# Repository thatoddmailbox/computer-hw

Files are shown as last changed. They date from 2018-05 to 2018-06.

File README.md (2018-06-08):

# computer-hw
Hardware for the Soviet-era microcomputer I built. See [this repository](https://github.com/thatoddmailbox/computer) for more information.

Most of the files in this respository are in KiCad format and require KiCad 4.0.7 to view; however, if you just want to view the schematic, you can find a PDF version in the doc folder or linked in the list below.

## Helpful documentation
* [Schematic in PDF format](./doc/schematic.pdf)
* [Original plan for memory decoding](./doc/decoding_original_plan.jpeg)
* [Changes to memory decoding when ROM and RAM chips didn't work](./doc/decoding_workaround.jpeg)
* [High-quality mechanical drawing for ZIF socket](./doc/zif_mechanical_drawing.jpeg)

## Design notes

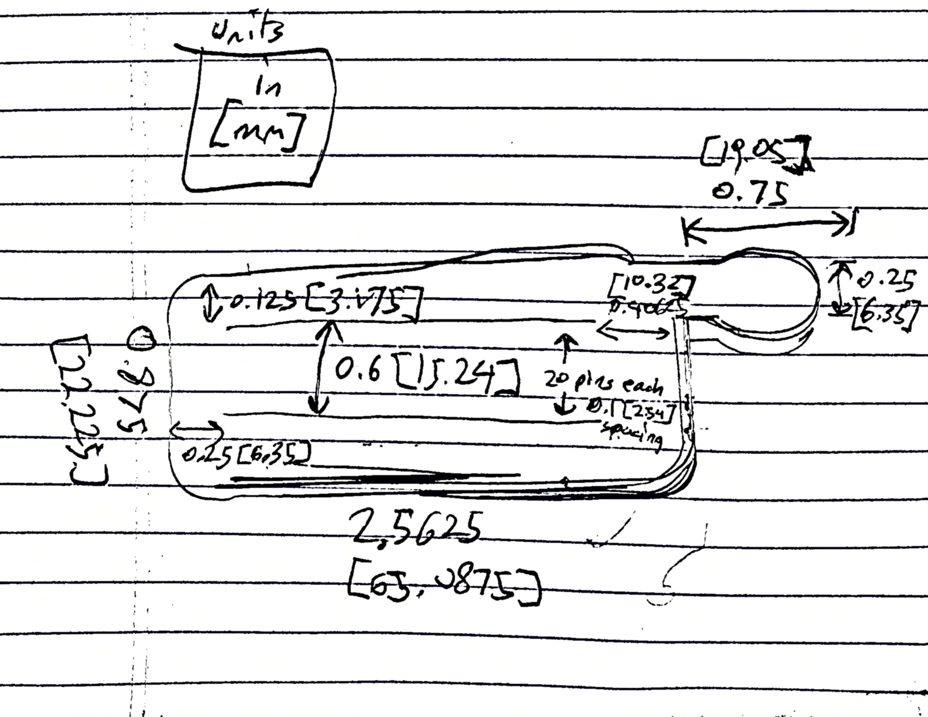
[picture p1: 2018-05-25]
doc/zif_mechanical_drawing.jpeg

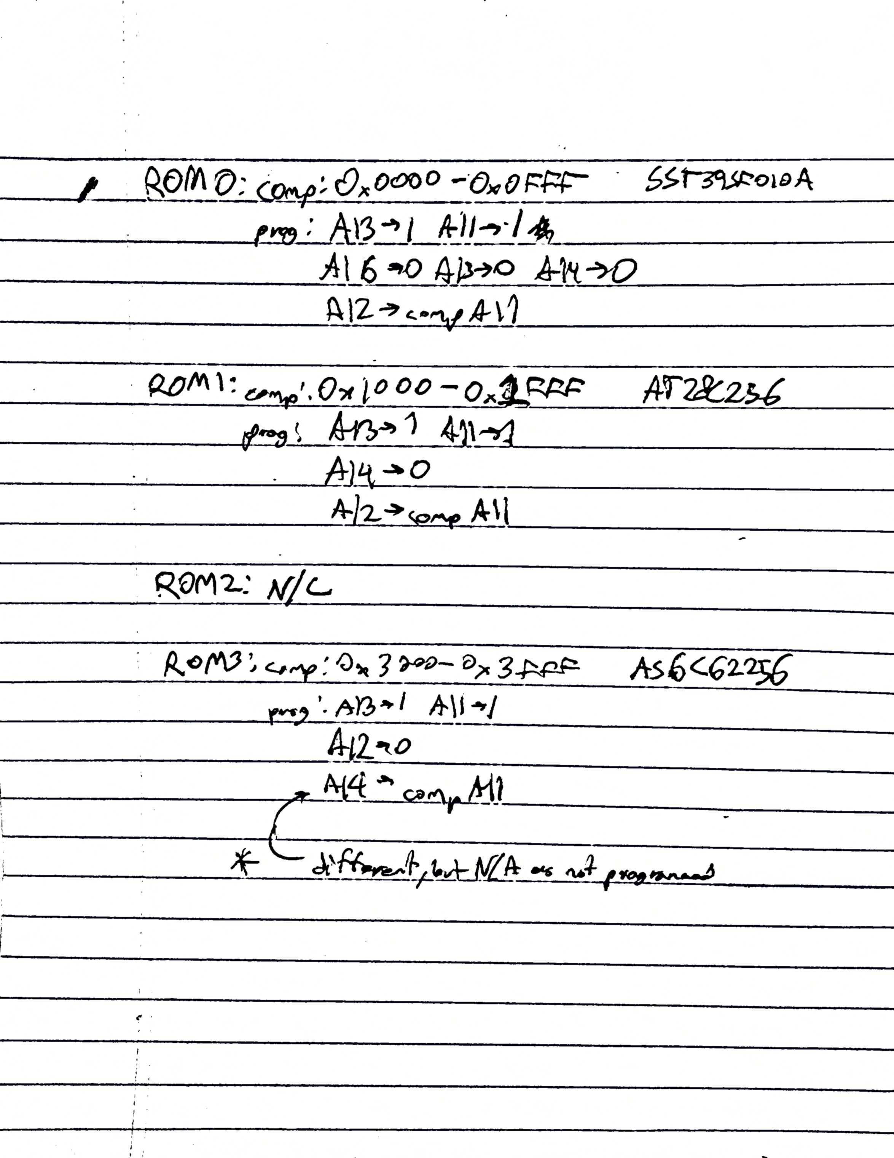
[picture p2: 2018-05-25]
doc/decoding_workaround.jpeg

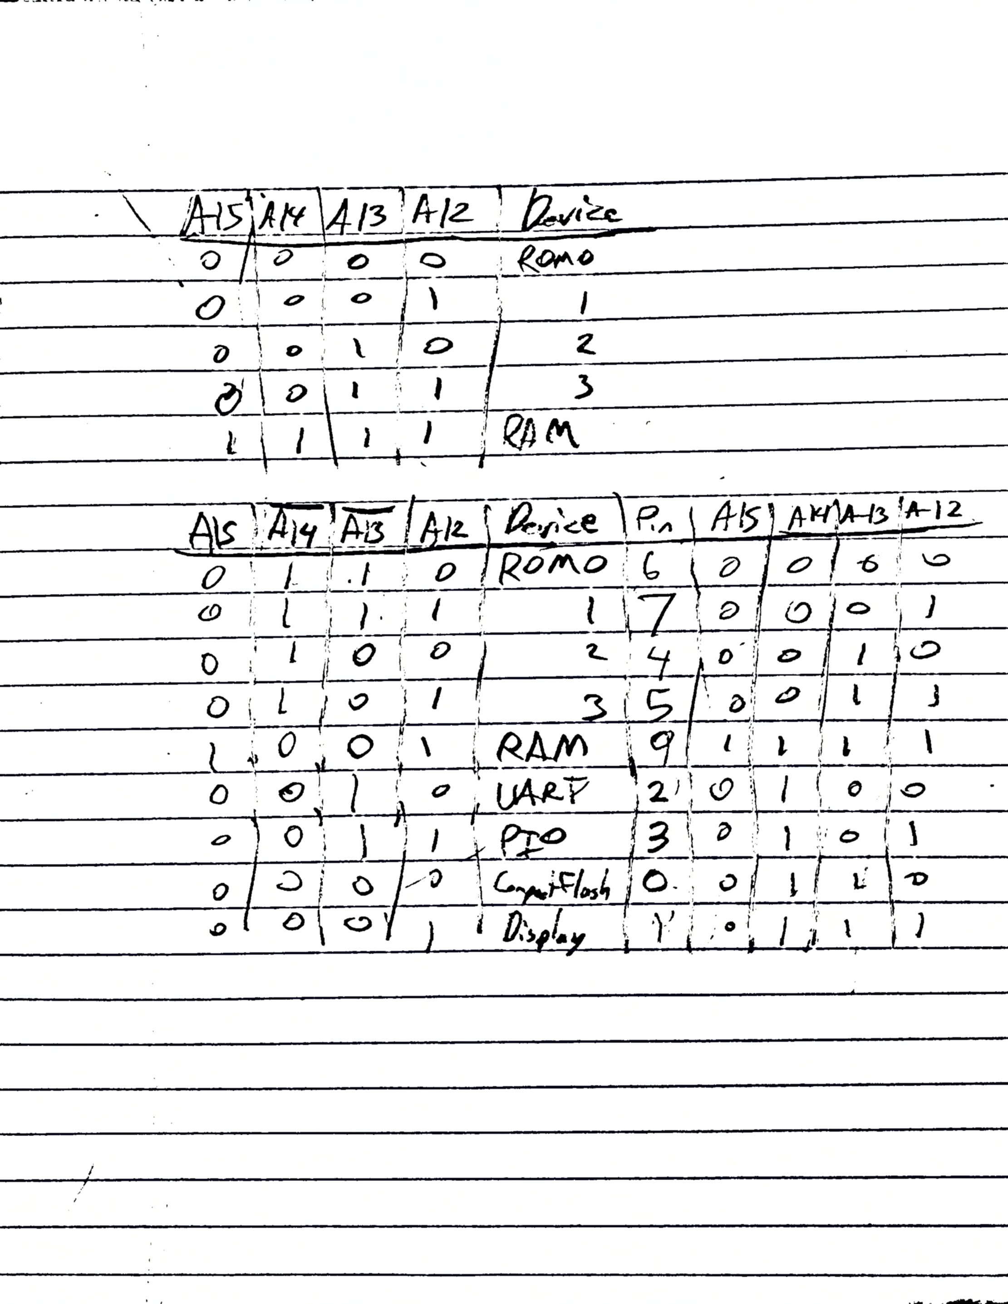
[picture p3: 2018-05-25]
doc/decoding_original_plan.jpeg

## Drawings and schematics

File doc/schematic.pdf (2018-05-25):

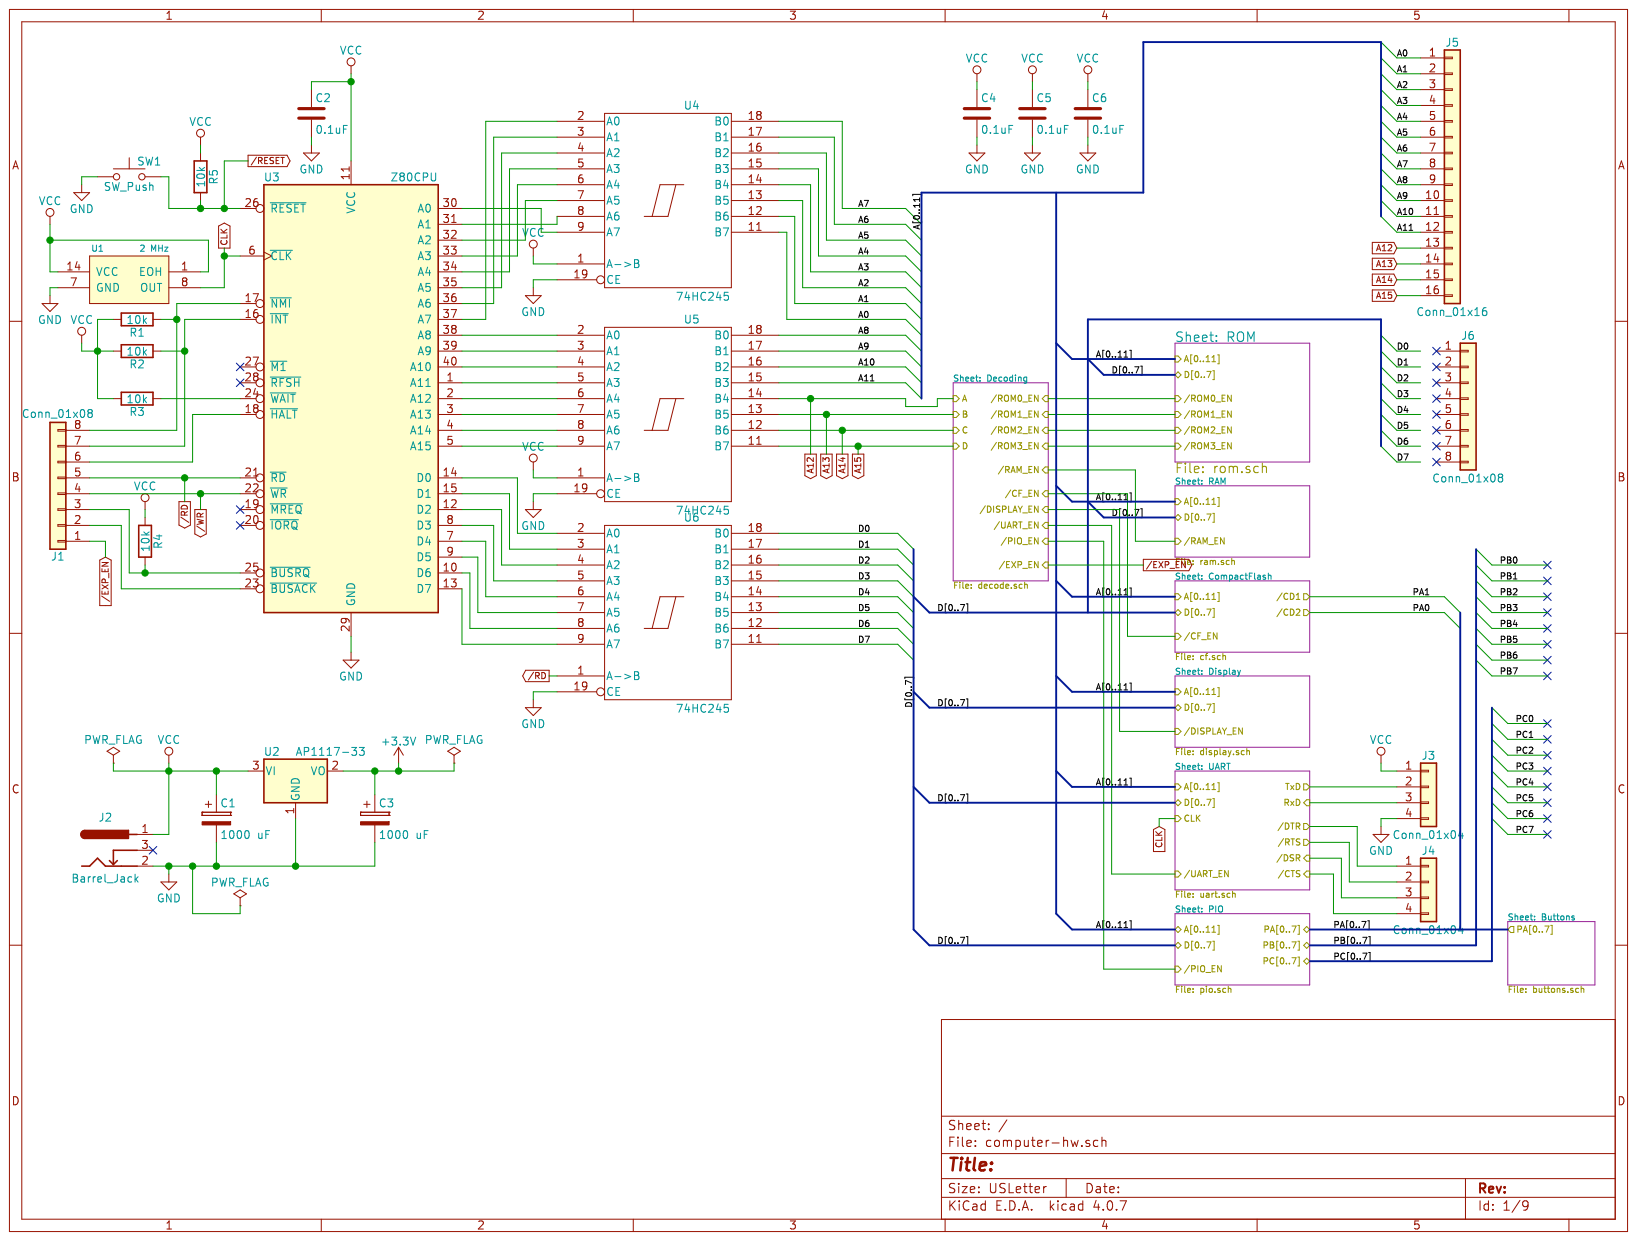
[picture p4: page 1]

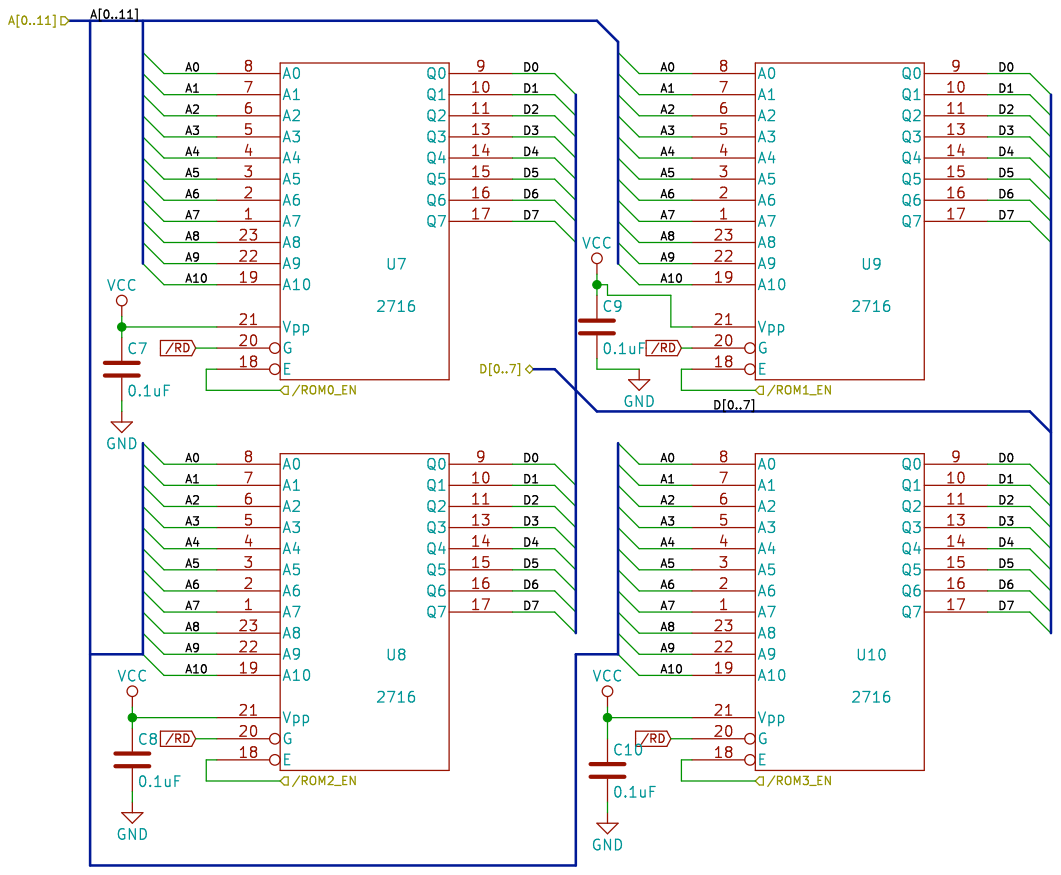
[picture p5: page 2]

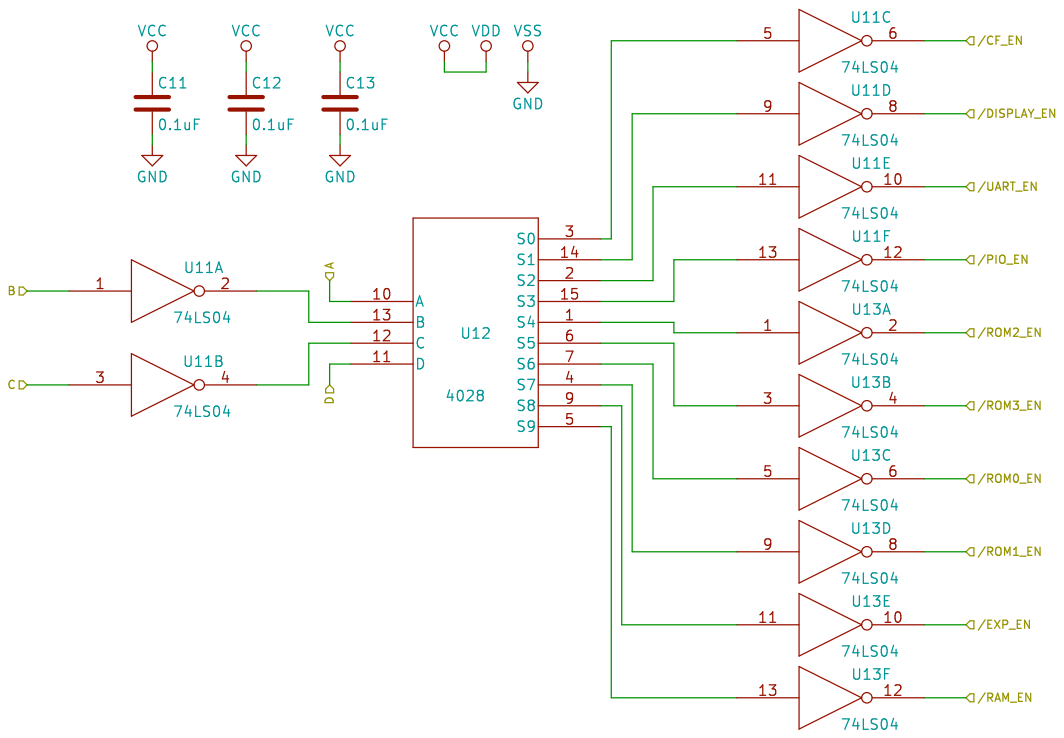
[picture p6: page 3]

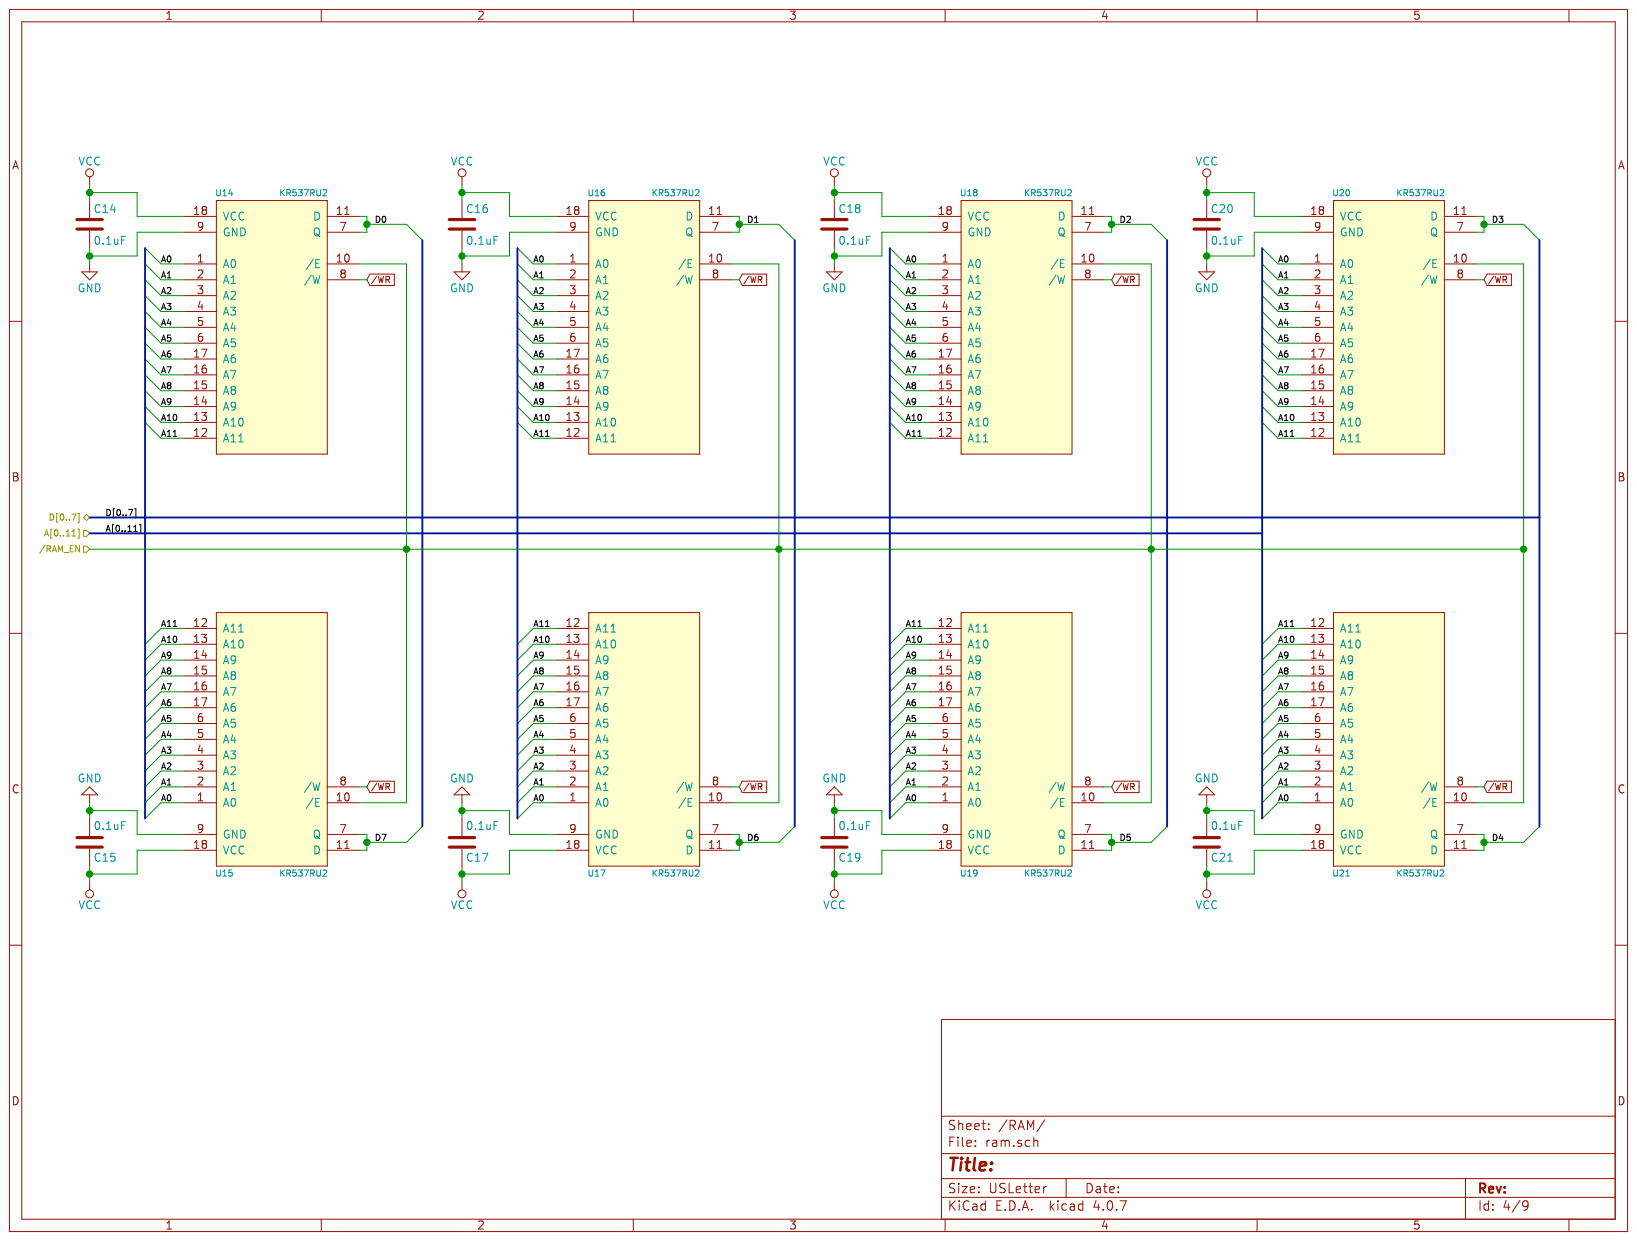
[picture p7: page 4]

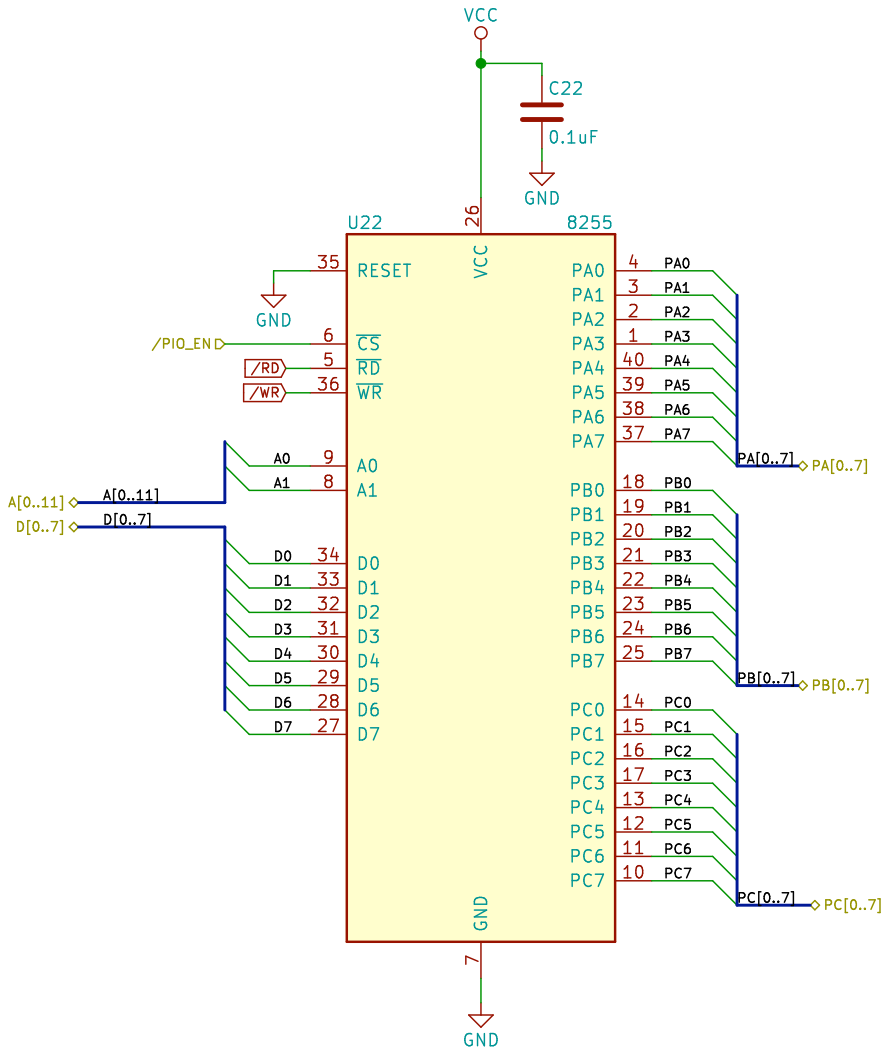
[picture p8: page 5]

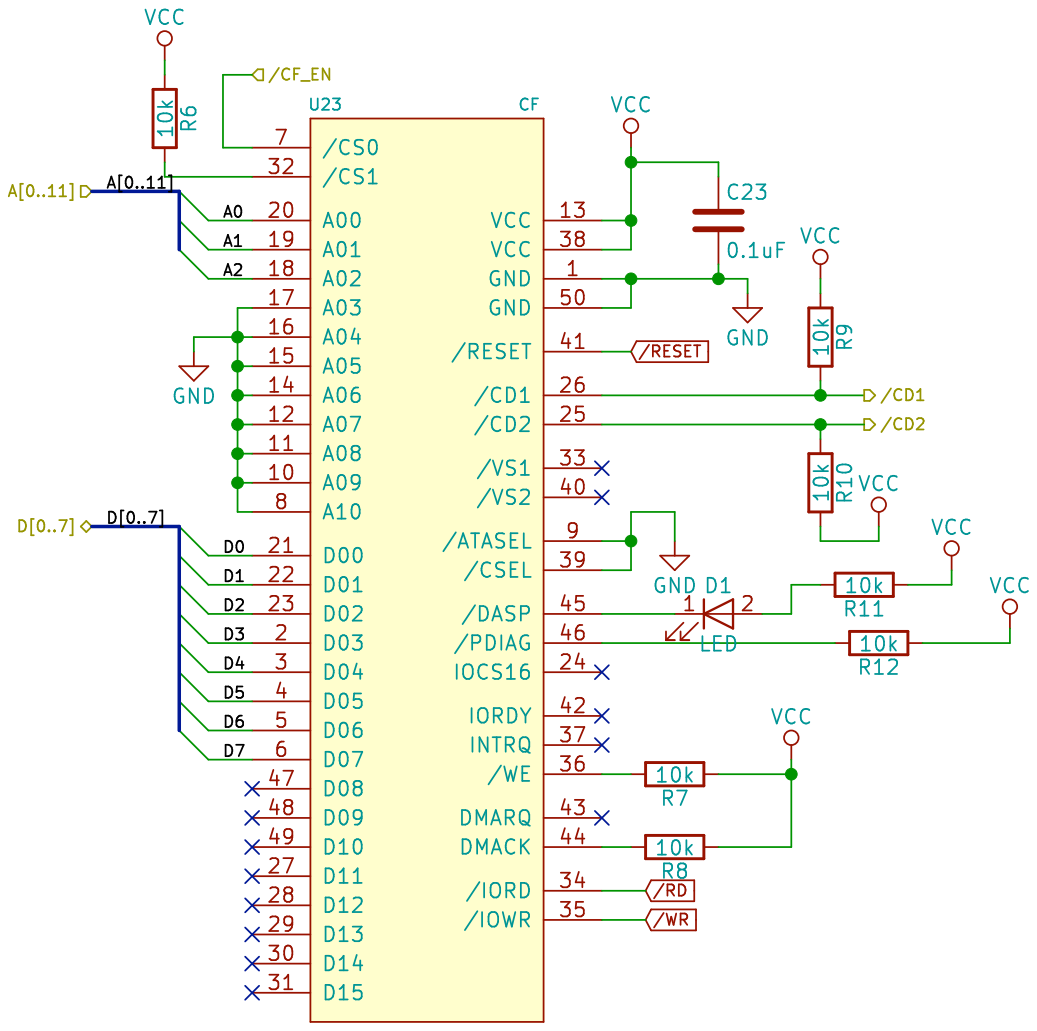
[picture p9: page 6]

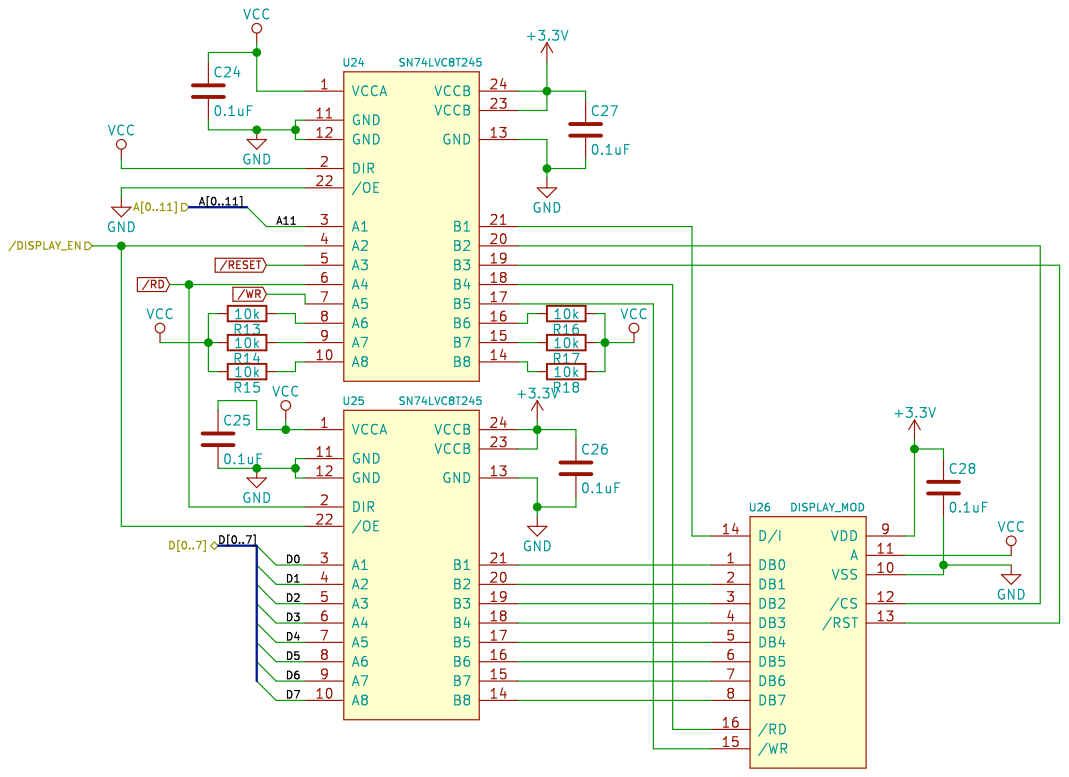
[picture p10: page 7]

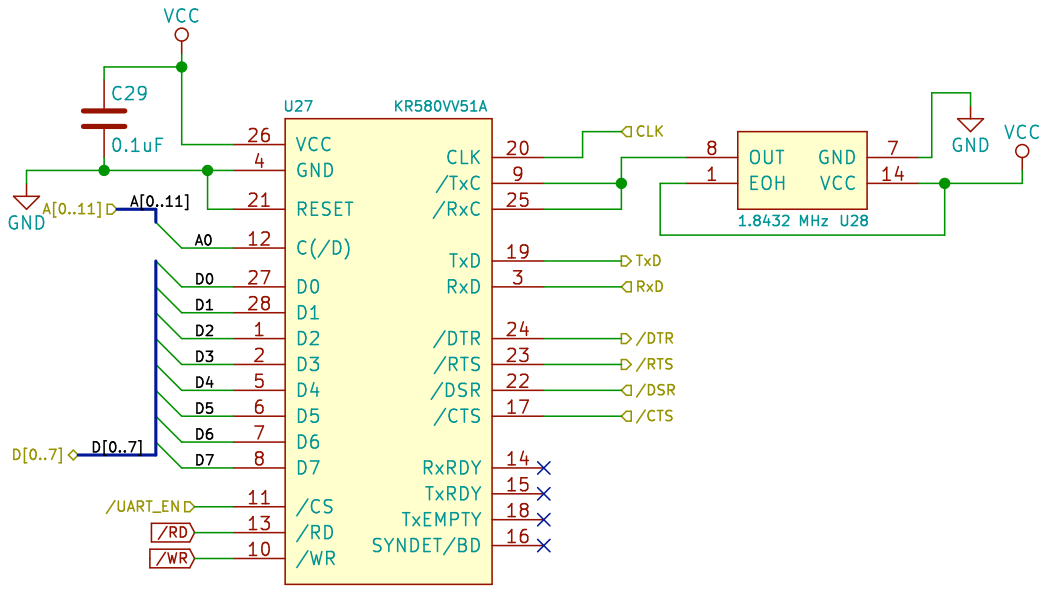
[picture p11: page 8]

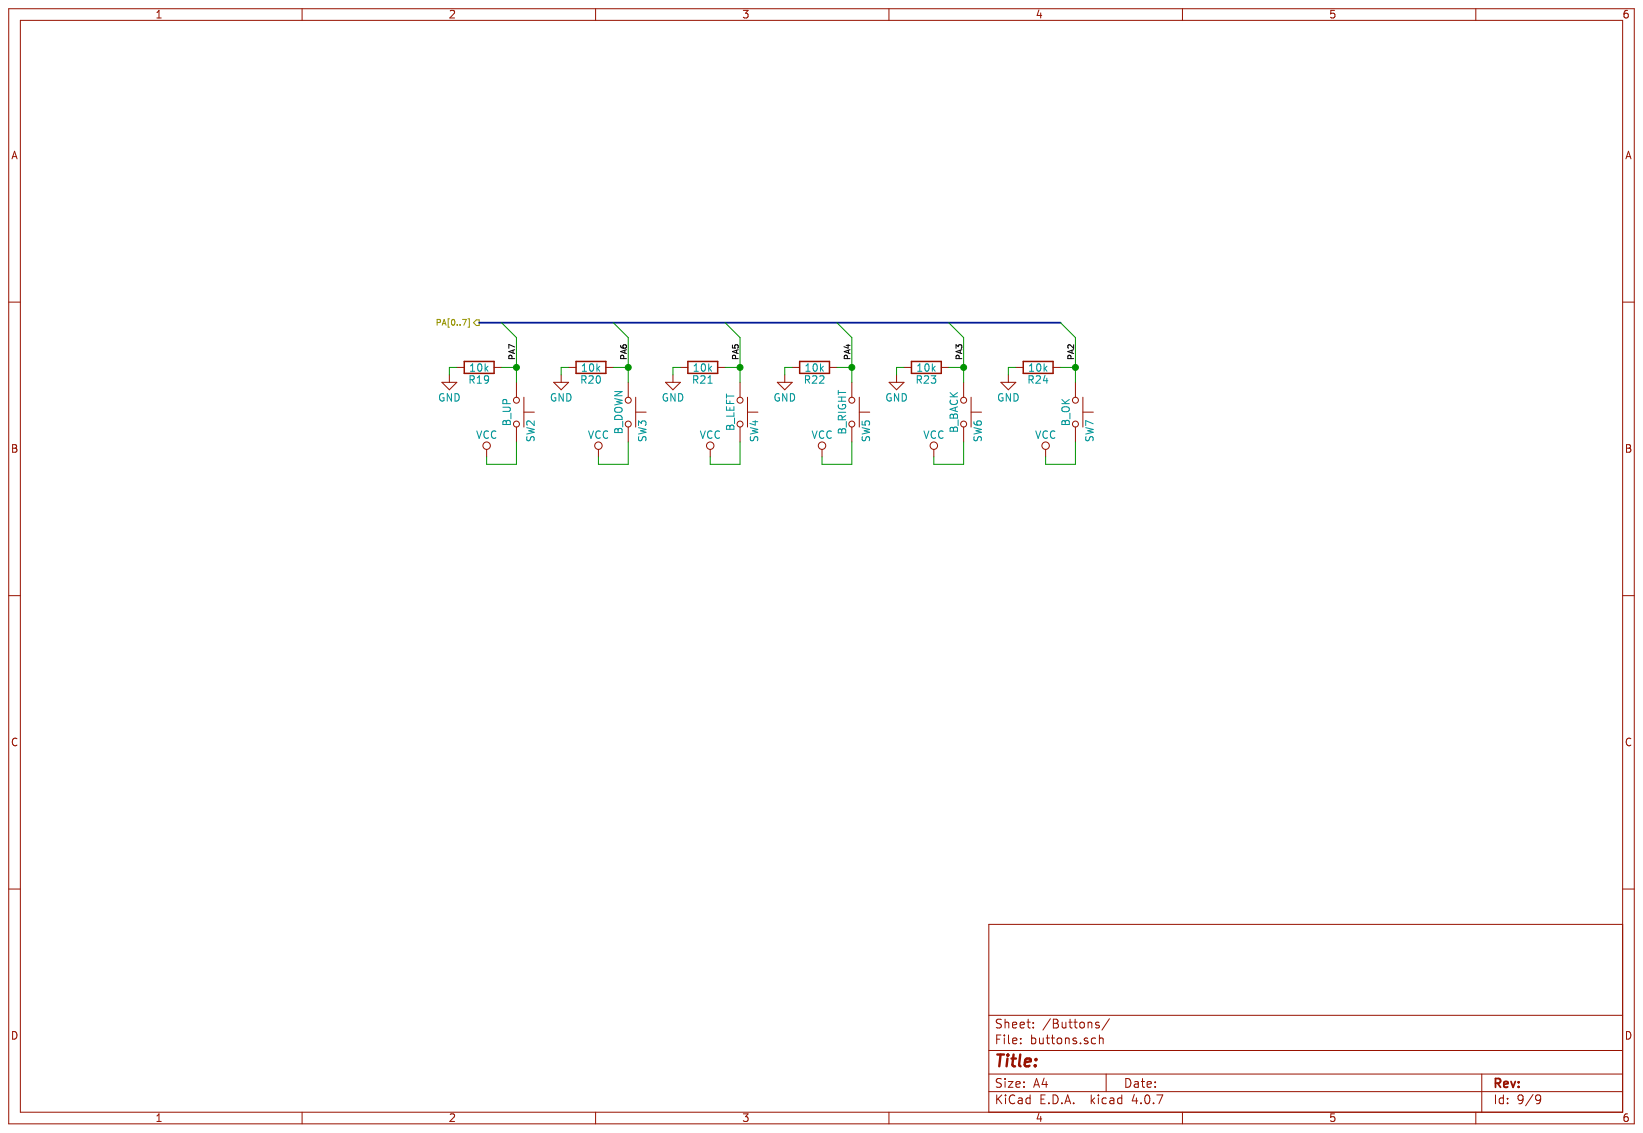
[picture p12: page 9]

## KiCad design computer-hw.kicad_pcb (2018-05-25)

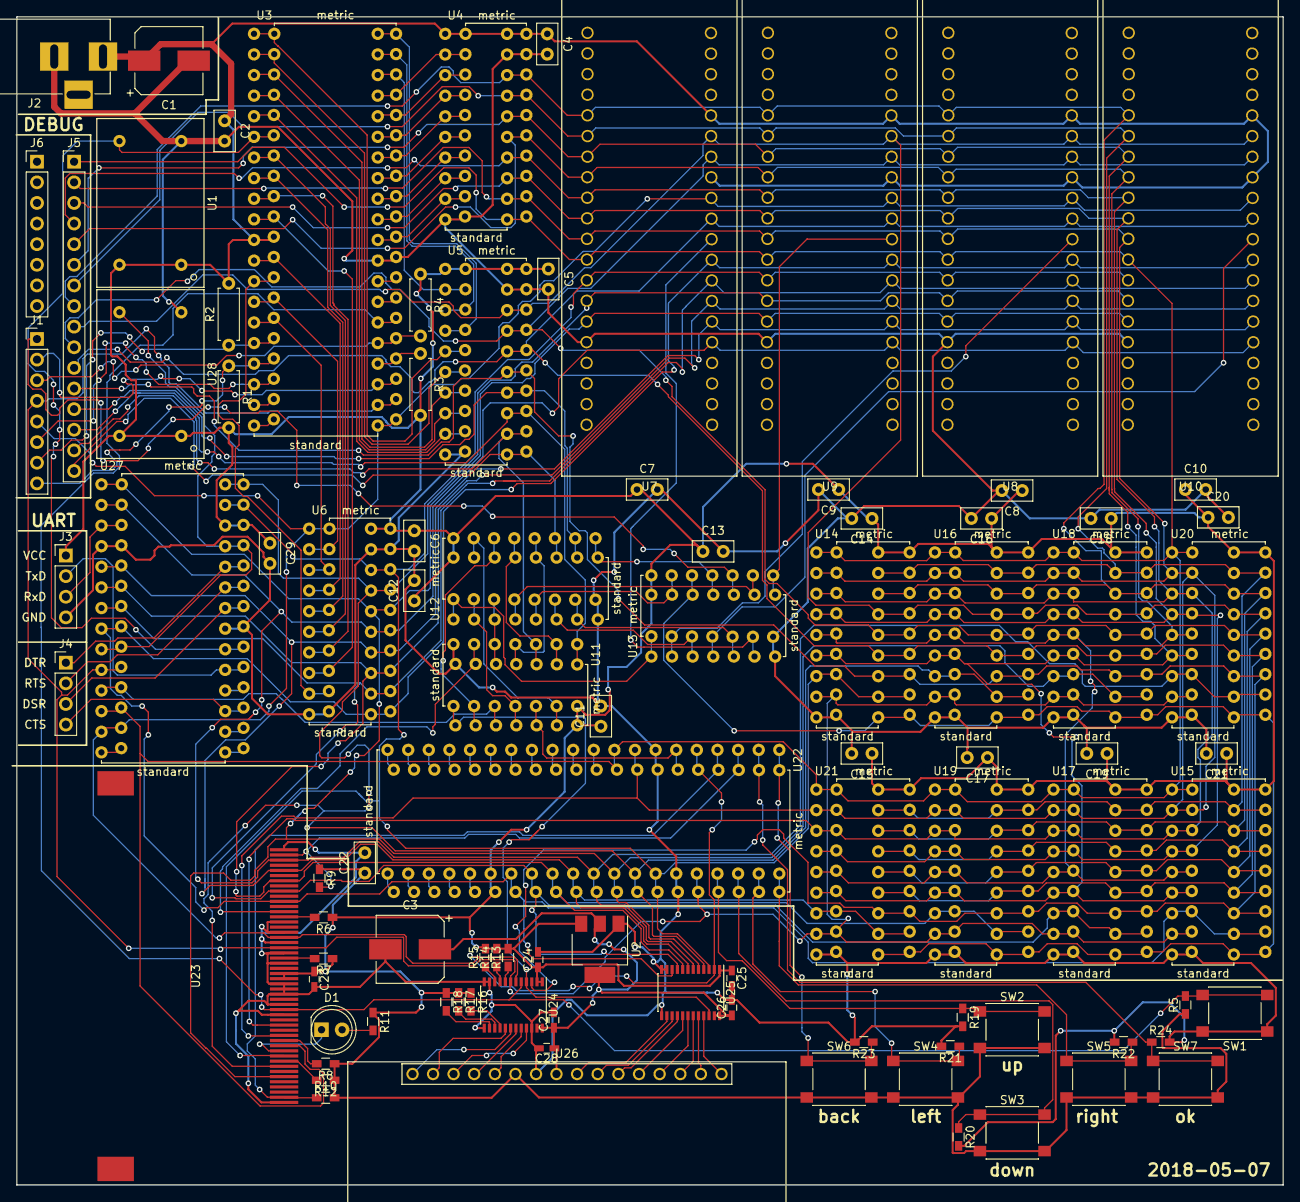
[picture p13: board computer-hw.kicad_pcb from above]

Board: 2 copper layers, 156.0 x 143.9 mm, 95 parts (0 on the bottom side), 123 nets.

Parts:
C1, C3: 1000 uF; CP_Elec_8x10
C2, C4, C5, C6, C7, C8, C9, C10, C11, C12, C13, C14, C15, C16, C17, C18, C19, C20, C21, C22, C29: 0.1uF; C_Disc_D5.0mm_W2.5mm_P2.50mm
C23, C24, C25, C26, C27, C28: 0.1uF; C_0603_HandSoldering
D1: LED; LED_D5.0mm
J1, J6: Conn_01x08; Pin_Header_Straight_1x08_Pitch2.54mm
J2: Barrel_Jack; BARREL_JACK
J3, J4: Conn_01x04; Pin_Header_Straight_1x04_Pitch2.54mm
J5: Conn_01x16; Pin_Header_Straight_1x16_Pitch2.54mm
R1, R2, R3, R4: 10k; R_Axial_DIN0207_L6.3mm_D2.5mm_P7.62mm_Horizontal
R5, R6, R7, R8, R9, R10, R11, R12, R13, R14, R15, R16, R17, R18, R19, R20, R21, R22, R23, R24: 10k; R_0603_HandSoldering
SW1: SW_Push; SW_SPST_PTS645
SW2: B_UP; SW_SPST_PTS645
SW3: B_DOWN; SW_SPST_PTS645
SW4: B_LEFT; SW_SPST_PTS645
SW5: B_RIGHT; SW_SPST_PTS645
SW6: B_BACK; SW_SPST_PTS645
SW7: B_OK; SW_SPST_PTS645
U1: 2 MHz; OSC
U2: AP1117-33; SOT-223-3_TabPin2
U3: Z80CPU; HYBRID_DIP40
U4, U5, U6: 74HC245; HYBRID_DIP20
U7, U8, U9, U10: 2716; ZIF40_DIP24
U11, U13: 74LS04; HYBRID_DIP14
U12: 4028; HYBRID_DIP16
U14, U15, U16, U17, U18, U19, U20, U21: KR537RU2; HYBRID_WEIRD_RAM
U22: 8255; HYBRID_DIP40
U23: CF
U24, U25: SN74LVC8T245; TSSOP-24_4.4x7.8mm_Pitch0.65mm
U26: DISPLAY_MOD
U27: KR580VV51A; HYBRID_DIP28
U28: 1.8432 MHz; OSC

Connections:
+3V3: C3.1, C26.1, C27.1, C28.1, U2.2, U24.23, U24.24, U25.23, U25.24, U26.9
/A0: J5.1, U4.11, U7.8, U8.8, U9.8, U10.8, U14.1, U15.1, U16.1, U17.1, U18.1, U19.1, U20.1, U21.1, U22.9, U23.20, U27.12
/A1: J5.2, U4.12, U7.7, U8.7, U9.7, U10.7, U14.2, U15.2, U16.2, U17.2, U18.2, U19.2, U20.2, U21.2, U22.8, U23.19
/A2: J5.3, U4.13, U7.6, U8.6, U9.6, U10.6, U14.3, U15.3, U16.3, U17.3, U18.3, U19.3, U20.3, U21.3, U23.18
/A3: J5.4, U4.14, U7.5, U8.5, U9.5, U10.5, U14.4, U15.4, U16.4, U17.4, U18.4, U19.4, U20.4, U21.4
/A4: J5.5, U4.15, U7.4, U8.4, U9.4, U10.4, U14.5, U15.5, U16.5, U17.5, U18.5, U19.5, U20.5, U21.5
/A5: J5.6, U4.16, U7.3, U8.3, U9.3, U10.3, U14.6, U15.6, U16.6, U17.6, U18.6, U19.6, U20.6, U21.6
/A6: J5.7, U4.17, U7.2, U8.2, U9.2, U10.2, U14.17, U15.17, U16.17, U17.17, U18.17, U19.17, U20.17, U21.17
/A7: J5.8, U4.18, U7.1, U8.1, U9.1, U10.1, U14.16, U15.16, U16.16, U17.16, U18.16, U19.16, U20.16, U21.16
/A8: J5.9, U5.18, U7.23, U8.23, U9.23, U10.23, U14.15, U15.15, U16.15, U17.15, U18.15, U19.15, U20.15, U21.15
/A9: J5.10, U5.17, U7.22, U8.22, U9.22, U10.22, U14.14, U15.14, U16.14, U17.14, U18.14, U19.14, U20.14, U21.14
/A10: J5.11, U5.16, U7.19, U8.19, U9.19, U10.19, U14.13, U15.13, U16.13, U17.13, U18.13, U19.13, U20.13, U21.13
/A11: J5.12, U5.15, U14.12, U15.12, U16.12, U17.12, U18.12, U19.12, U20.12, U21.12, U24.3
/Buttons/PA2: R24.1, SW7.1, U22.2
/Buttons/PA3: R23.1, SW6.1, U22.1
/Buttons/PA4: R22.1, SW5.1, U22.40
/Buttons/PA5: R21.1, SW4.1, U22.39
/Buttons/PA6: R20.1, SW3.1, U22.38
/Buttons/PA7: R19.1, SW2.1, U22.37
/CompactFlash//CF_EN: U11.6, U23.7
/D0: U6.18, U7.9, U8.9, U9.9, U10.9, U14.7, U14.11, U22.34, U23.21, U25.3, U27.27
/D1: U6.17, U7.10, U8.10, U9.10, U10.10, U16.7, U16.11, U22.33, U23.22, U25.4, U27.28
/D2: U6.16, U7.11, U8.11, U9.11, U10.11, U18.7, U18.11, U22.32, U23.23, U25.5, U27.1
/D3: U6.15, U7.13, U8.13, U9.13, U10.13, U20.7, U20.11, U22.31, U23.2, U25.6, U27.2
/D4: U6.14, U7.14, U8.14, U9.14, U10.14, U21.7, U21.11, U22.30, U23.3, U25.7, U27.5
/D5: U6.13, U7.15, U8.15, U9.15, U10.15, U19.7, U19.11, U22.29, U23.4, U25.8, U27.6
/D6: U6.12, U7.16, U8.16, U9.16, U10.16, U17.7, U17.11, U22.28, U23.5, U25.9, U27.7
/D7: U6.11, U7.17, U8.17, U9.17, U10.17, U15.7, U15.11, U22.27, U23.6, U25.10, U27.8
/Decoding//DISPLAY_EN: U11.8, U24.4, U25.22
/Decoding//PIO_EN: U11.12, U22.6
/Decoding//RAM_EN: U13.12, U14.10, U15.10, U16.10, U17.10, U18.10, U19.10, U20.10, U21.10
/Decoding//ROM0_EN: U7.18, U13.6
/Decoding//ROM1_EN: U9.18, U13.8
/Decoding//ROM2_EN: U8.18, U13.2
/Decoding//ROM3_EN: U10.18, U13.4
/Decoding//UART_EN: U11.10, U27.11
/EXP_EN: J1.1, U13.10
/PA0: R10.1, U22.4, U23.25
/PA1: R9.2, U22.3, U23.26
/RD: J1.5, U3.21, U6.1, U7.20, U8.20, U9.20, U10.20, U22.5, U23.34, U24.6, U25.2, U27.13
/RESET: R5.2, SW1.2, U3.26, U23.41, U24.5
/UART//CTS: J4.4, U27.17
/UART//DSR: J4.3, U27.22
/UART//DTR: J4.1, U27.24
/UART//RTS: J4.2, U27.23
/UART/RxD: J3.3, U27.3
/UART/TxD: J3.2, U27.19
/WR: J1.4, U3.22, U14.8, U15.8, U16.8, U17.8, U18.8, U19.8, U20.8, U21.8, U22.36, U23.35, U24.7, U27.10
A12: J5.13, U5.14, U12.10
A13: J5.14, U5.13, U11.1
A14: J5.15, U5.12, U11.3
A15: J5.16, U5.11, U12.11
CLK: U1.8, U3.6, U27.20
GND: C1.2, C2.2, C3.2, C4.2, C5.2, C6.2, C7.2, C8.2, C9.2, C10.2, C11.2, C12.2, C13.2, C14.2, C15.2, C16.2, C17.2, C18.2, C19.2, C20.2, C21.2, C22.2, C23.2, C24.2, C25.2, C26.2, C27.2, C28.2, C29.2, J2.2, J3.4, R19.2, R20.2, R21.2, R22.2, R23.2, R24.2, SW1.1, U1.7, U2.1, U3.29, U4.10, U4.19, U5.10, U5.19, U6.10, U6.19, U7.12, U8.12, U9.12, U10.12, U11.7, U12.8, U13.7, U14.9, U15.9, U16.9, U17.9, U18.9, U19.9, U20.9, U21.9, U22.7, U22.35, U23.1, U23.8, U23.9, U23.10, U23.11, U23.12, U23.14, U23.15, U23.16, U23.17, U23.39, U23.50, U24.11, U24.12, U24.13, U24.22, U25.11, U25.12, U25.13, U26.10, U27.4, U27.21, U28.7
unnamed: D1.1, U23.45
unnamed: D1.2, R11.2
unnamed: J1.2, U3.23
unnamed: J1.3, R4.2, U3.25
unnamed: J1.6, U3.18
unnamed: J1.7, R2.1, U3.16
unnamed: J1.8, R1.1, U3.17
unnamed: R3.1, U3.24
unnamed: R6.2, U23.32
unnamed: R7.2, U23.36
unnamed: R8.2, U23.44
unnamed: R12.2, U23.46
unnamed: R13.1, U24.8
unnamed: R14.1, U24.9
unnamed: R15.1, U24.10
unnamed: R16.2, U24.16
unnamed: R17.2, U24.15
unnamed: R18.2, U24.14
unnamed: U3.1, U5.5
unnamed: U3.2, U5.6
unnamed: U3.3, U5.7
unnamed: U3.4, U5.8
unnamed: U3.5, U5.9
unnamed: U3.7, U6.6
unnamed: U3.8, U6.5
unnamed: U3.9, U6.7
unnamed: U3.10, U6.8
unnamed: U3.12, U6.4
unnamed: U3.13, U6.9
unnamed: U3.14, U6.2
unnamed: U3.15, U6.3
unnamed: U3.30, U4.9
unnamed: U3.31, U4.8
unnamed: U3.32, U4.7
unnamed: U3.33, U4.6
unnamed: U3.34, U4.5
unnamed: U3.35, U4.4
unnamed: U3.36, U4.3
unnamed: U3.37, U4.2
unnamed: U3.38, U5.2
unnamed: U3.39, U5.3
unnamed: U3.40, U5.4
unnamed: U11.2, U12.13
unnamed: U11.4, U12.12
unnamed: U11.5, U12.3
unnamed: U11.9, U12.14
unnamed: U11.11, U12.2
unnamed: U11.13, U12.15
unnamed: U12.1, U13.1
unnamed: U12.4, U13.9
unnamed: U12.5, U13.13
unnamed: U12.6, U13.3
unnamed: U12.7, U13.5
unnamed: U12.9, U13.11
unnamed: U24.17, U26.15
unnamed: U24.18, U26.16
unnamed: U24.19, U26.13
unnamed: U24.20, U26.12
unnamed: U24.21, U26.14
unnamed: U25.14, U26.8
unnamed: U25.15, U26.7
unnamed: U25.16, U26.6
unnamed: U25.17, U26.5
unnamed: U25.18, U26.4
unnamed: U25.19, U26.3
unnamed: U25.20, U26.2
unnamed: U25.21, U26.1
unnamed: U27.9, U27.25, U28.8
VCC: C1.1, C2.1, C4.1, C5.1, C6.1, C7.1, C8.1, C9.1, C10.1, C11.1, C12.1, C13.1, C14.1, C15.1, C16.1, C17.1, C18.1, C19.1, C20.1, C21.1, C22.1, C23.1, C24.1, C25.1, C29.1, J2.1, J3.1, R1.2, R2.2, R3.2, R4.1, R5.1, R6.1, R7.1, R8.1, R9.1, R10.2, R11.1, R12.1, R13.2, R14.2, R15.2, R16.1, R17.1, R18.1, SW2.2, SW3.2, SW4.2, SW5.2, SW6.2, SW7.2, U1.1, U1.14, U2.3, U3.11, U4.1, U4.20, U5.1, U5.20, U6.20, U7.21, U7.24, U8.21, U8.24, U9.21, U9.24, U10.21, U10.24, U11.14, U12.16, U13.14, U14.18, U15.18, U16.18, U17.18, U18.18, U19.18, U20.18, U21.18, U22.26, U23.13, U23.38, U24.1, U24.2, U25.1, U26.11, U27.26, U28.1, U28.14

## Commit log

2018-05-25 commit original layout files
    [buttons.sch, cf.sch, computer-hw.kicad_pcb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]
2018-05-25 add fixes so that the pcb actually meets the design rules
    [computer-hw.kicad_pcb]
2018-05-25 add schematic in pdf format
2018-06-07 move documentation into separate folder and add schematic link to readme
